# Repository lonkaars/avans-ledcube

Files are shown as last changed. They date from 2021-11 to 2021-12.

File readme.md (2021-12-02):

# avans-ledcube

(in dutch again haha)

onze ledcube is iets anders dan de gemiddelde ledcube. onze leds zijn
aangesloten als een 8x8 matrix waarbij alle anodes in rijen, en alle cathodes
in kolommen zijn verbonden. hierdoor gebruikt onze ledcube maar acht
weerstanden inplaats van zestien, en geen transistoren of mosfets. ook worden
maar drie uitgangen van de arduino gebruikt voor de seriële ingang, seriële
klok, en de latch klok van het shiftregister.

## coole functies

- algoritme om lege scanrijen over te slaan voor een hogere felheid
- instelbare lengte en volgorde van de effecten die afspelen
- makkelijk uitbereidbaar met nieuwe effecten
- goed gedocumenteerd
- opgesplitst in losse bestanden voor overzichtelijkheid
- ingebouwde led map zodat je coordinaten kunt gebruiken in je animatiecode
- veganistisch vriendelijk

## software

de software is als gevolg van de ongewone aansluitingswijze ook anders
ingericht. de atmega328p heeft ingebouwde pwm timers, die je zou kunnen
gebruiken om snel door de vier lagen van de ledcube heen te schakelen. omdat
deze timers los van je code draaien kun je de ingebouwde `delay()` gewoon
gebruiken om de animaties makkelijker te implementeren, maar dit werkt alleen
wanneer je transistoren gebruikt en ze direct op pwm uitgangen aansluit.

daarom gebruikt onze software geen `delay()` of andere 'blokkerende' functies,
maar timers. dit zorgt ervoor dat de ingebouwde `loop()` functie van de arduino
vaak genoeg draait om het te laten lijken alsof alle led's van de ledcube
tegelijkertijd aan zijn.

de software is opgesplitst in losse bestanden om overzichtelijkheid te
behouden. alle documentatie bevindt zich in de header (.h) bestanden, is in het
engels, en is in doxygen formaat. hier is een beknopte beschrijving van de
bestanden:

```
software/
├── animation.h      --
├── animation.ino    helpfuncties voor animaties
├── consts.h         algemene constantes
├── effects.h        bevat ook opties voor de diavoorstelling van animaties
├── effects.ino      de animaties die weergeven worden
├── readme.md        dit bestand
├── scan.h           --
├── scan.ino         functies omtrent het schakelen van de rijen
├── shift.h          --
├── shift.ino        functies die het shiftregister besturen
├── software.h       --
├── software.ino     hoofdbestand/ingangspunt
├── util.h           --
└── util.ino         gereedschapsfuncties
```

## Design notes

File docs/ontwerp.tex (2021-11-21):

\documentclass[12pt, a4paper, dutch]{article}

\usepackage[margin=1in]{geometry}
\usepackage{circuitikz}
\usepackage{float}
\usepackage{babel}
\usepackage{siunitx}
\usepackage{amsmath}
\usepackage{scalerel}
\usepackage{csquotes}
\usepackage{parskip}
\usepackage{unicode-math}
\usepackage{fontspec}
\usepackage{tabularx}
\usepackage{booktabs}
\usepackage{graphicx}
\usepackage{pgfplots}
\usepackage{color}
\usepackage{hyperref}

\setmainfont{TeX Gyre Schola}
\setmathfont{TeX Gyre Schola Math}
\setmonofont{JetBrainsMono Nerd Font}
\sisetup{
	group-separator = {.},
	output-decimal-marker = {,}
}

\pgfplotsset{compat=newest}

\usetikzlibrary{calc}
\usetikzlibrary{shapes.geometric}
\usetikzlibrary{arrows.meta,arrows}
\usetikzlibrary{positioning}
\tikzset{
	initial/.style={circle, fill},
	final/.style={solid, double=white, circle, fill, thick, draw},
	decision/.style={diamond, black, draw},
	action/.style={rectangle, draw, rounded corners, align=center},
	arrow/.style={draw, -{Latex[length=3mm]}, thick, rounded corners}
}

\bigskipamount=7mm
\medskipamount=4mm
\parindent=0mm

\begin{document}

\begin{center}
\textbf{Ontwerp} \hspace{2mm} project ledcube \hfill \textbf{Loek Le Blansch}
(2180996)\\
\today \hfill \textbf{Sybren van den Heuvel} (2191465)
\end{center}

\medskip

Dit document maakt gebruik van hyperlinks, dus je kunt klikken op de blokken met
\emph{benadrukte tekst} om naar de definitie van dat blok te gaan.

\section{Software ontwerp}

\subsection*{Overzicht}\label{overzicht}
\begin{center}
\begin{tikzpicture}[node distance=1.5cm]
\node[initial] (initial) at (0,0) {};
\node[action, below of = initial] (setup) {\hyperref[init]{\emph{Initialisatie}}};
\node[decision, below of = setup] (comb) {};
\node[action, below of = comb] (loop) {\hyperref[loop]{\emph{Loop}}};

\draw [arrow] (initial) -- (setup);
\draw [arrow] (setup) -- (comb);
\draw [arrow] (comb) -- (loop);
\draw [arrow] (loop) -- ++(0, -1) -- ++(-2, 0) |- (comb);

\end{tikzpicture}
\end{center}

\subsection*{Initialisatie}\label{init}
\begin{center}
\begin{tikzpicture}[node distance=1.5cm]
\node[initial] (initial) at (0,0) {};

\node[action, below = 1cm of initial] (mkvars) {Maak globale variabelen voor\\de
	huidige staat van de led's};

\node[action, below = 1cm of mkvars] (pinmode) {Stel pin 2, 3, en 4 in als
	output\\voor het shiftregister};

\node[action, below = 1cm of pinmode] (frametimecalc) {Bereken hoe lang een beeld
	duurt\\in milliseconden afhankelijk van\\de verversingssnelheid};

\node[final, below of = frametimecalc] (final) {};

\draw [arrow] (initial) -- (mkvars);
\draw [arrow] (mkvars) -- (pinmode);
\draw [arrow] (pinmode) -- (frametimecalc);
\draw [arrow] (frametimecalc) -- (final);

\end{tikzpicture}
\end{center}

\subsection*{Loop}\label{loop}
\begin{center}
\begin{tikzpicture}[node distance=2cm]
\node[initial] (initial) at (0,0) {};

\node[action, below of = initial] (gettime)
	{Sla op hoe lang de arduino\\aan is in milliseconden};

\node[action, below of = gettime] (calcfxindex)
	{Bereken welk effect afgespeeld moet worden};

\node[action, below of = calcfxindex] (calcfxtime)
	{Bereken hoe lang het huidige effect al bezig is};

\node[action, below of = calcfxtime] (fxexec)
	{Voer de functie van het huidige effect uit};

\node[action, below of = fxexec] (updateregs)
	{Update de status van de led's};

\node[final, below of = updateregs] (final) {};

\draw [arrow] (initial) -- (gettime);
\draw [arrow] (gettime) -- (calcfxindex);
\draw [arrow] (calcfxindex) -- (calcfxtime);
\draw [arrow] (calcfxtime) -- (fxexec);
\draw [arrow] (fxexec) -- (updateregs);
\draw [arrow] (updateregs) -- (final);

\end{tikzpicture}
\end{center}

\section{Hardware}

\subsection{Schema}

\begin{center}
\includegraphics[
	clip,
	trim=21mm 83mm 22mm 13mm,
	width=\textwidth
]{./schema.pdf}
\end{center}

\subsection{PCB}
\begin{center}
\includegraphics[
	clip,
	trim=13mm 119mm 124mm 13mm,
	width=\textwidth
]{./pcb.pdf}
\end{center}

\subsection{Bedrading (3D)}

Dit is een 3D-weergave van de bedrading van de led cube. In deze weergave zie je
duidelijk dat de led cube bestaat uit een 8$\times$8-matrix die twee keer is
dubbelgevouwd. Hier zijn de roze verbindingen de anode's van de led's, en de blauwe
de cathode's.

\begin{center}
\includegraphics[
	width=0.4\textwidth
]{./red.png}
\hspace{1cm}
\includegraphics[
	width=0.4\textwidth
]{./blue.png}
\end{center}

\section{Functiebeschrijving}

\includegraphics[
	clip,
	trim=24.5mm 180mm 24.5mm 24.5mm,
	width=\textwidth
]{./functiebeschrijving.pdf}

\section{Blokschema}

\includegraphics[
	width=\textwidth
]{./blokschema.jpeg}

\end{document}

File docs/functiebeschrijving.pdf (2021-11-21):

| Waarom zit onderdeel in de Ledcube? | Hoe is het onderdeel opgebouwd? Wat is het voor onderdeel? Hoe ziet het er uit? | Wat doet het onderdeel?
Shiftregister | Het shiftregister zit in de Ledcube om het aantal uitgangen te vergroten en zo de ledjes individueel aan te sturen. | Een shiftregister is digitaal circuit van een reeks flipflops achter elkaar. Waarbij de ene uitgang van de flipflop is verbonden met de ingang van de volgende. | Een shiftregister is een register met een kloksignaal, wat zorgt dat de data in het register (bits) van de ene plek naar de andere plek kan ‘’shiften’’ en kan ze tijdelijk opslaan.
Led | De ledjes zitten in de Ledcube om de animaties op weer te geven. | Een light emmiting diode (Led) | De led zal de animaties visualiseren.

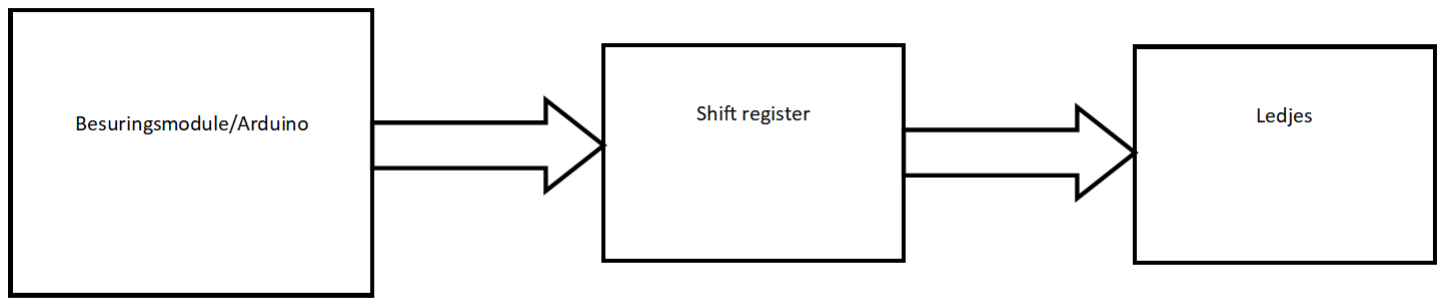
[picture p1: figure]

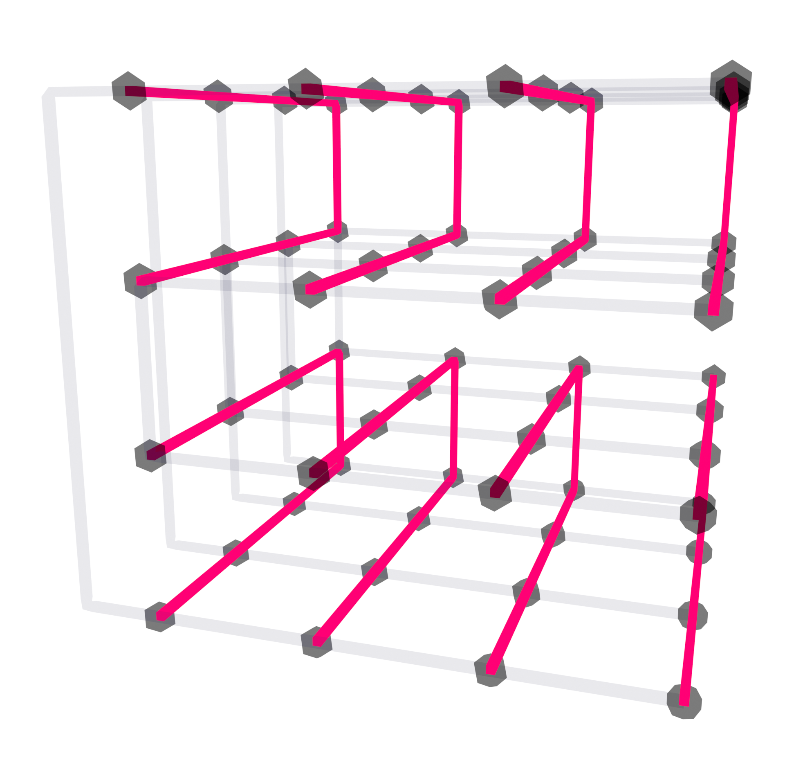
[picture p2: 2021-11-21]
docs/red.png

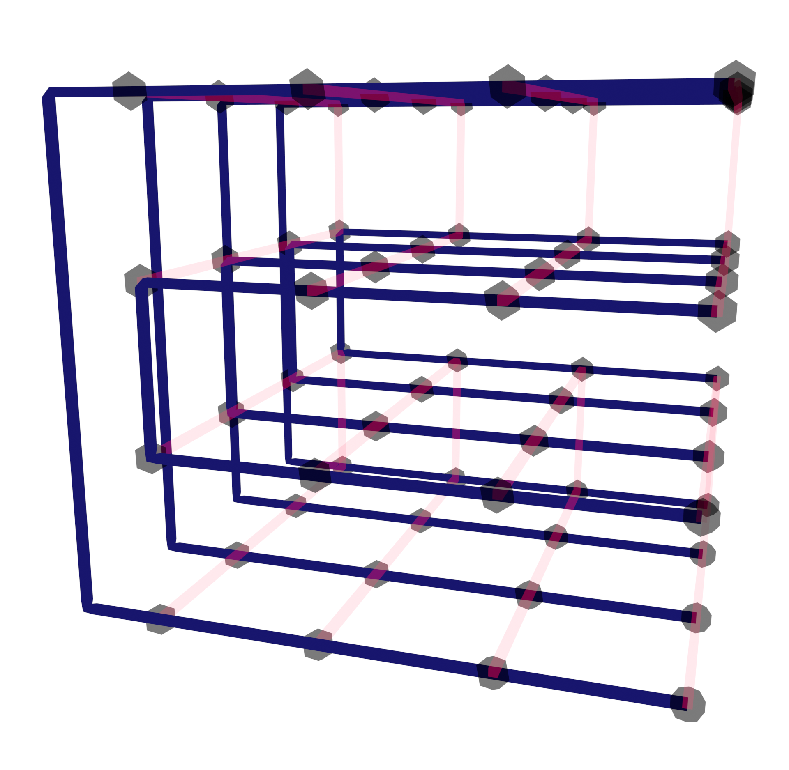
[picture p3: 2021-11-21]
docs/blue.png

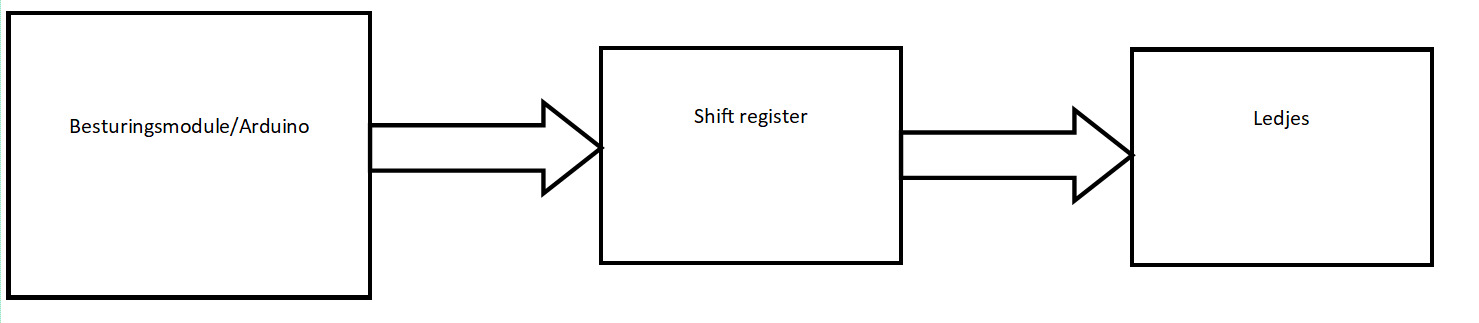
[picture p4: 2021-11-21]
docs/blokschema.jpeg

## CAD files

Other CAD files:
hardware/wiring.blend

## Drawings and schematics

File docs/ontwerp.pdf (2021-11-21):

Ontwerp project ledcube | Loek Le Blansch (2180996)
21 november 2021 | Sybren van den Heuvel (2191465)

Dit document maakt gebruik van hyperlinks, dus je kunt klikken op de blokken met benadrukte tekst om naar de definitie van dat blok te gaan.

## 1 Software ontwerp

### Overzicht

Initialisatie

Loop

### Initialisatie

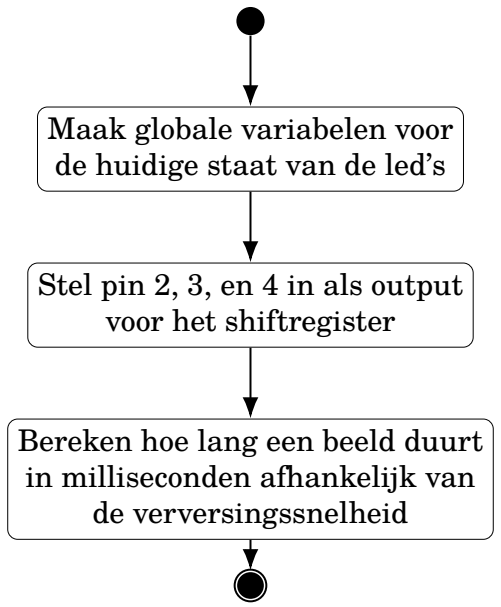
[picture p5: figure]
Maak globale variabelen voor de huidige staat van de led’s; Stel pin 2, 3, en 4 in als output voor het shiftregister; Bereken hoe lang een beeld duurt in milliseconden afhankelijk van de verversingssnelheid
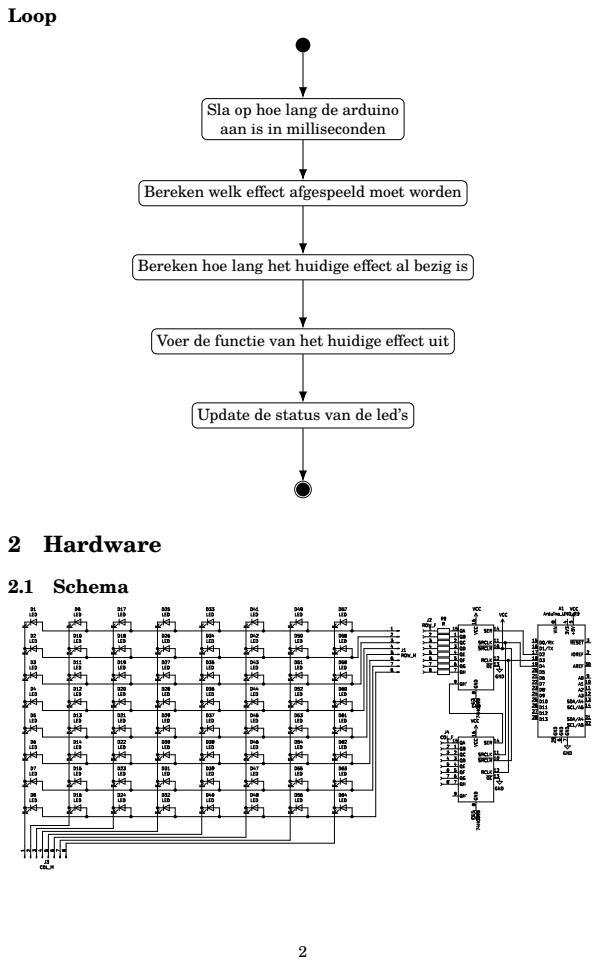
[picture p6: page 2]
Loop; 2 Hardware; 2.1 Schema

Sla op hoe lang de arduino
aan is in milliseconden

Bereken welk effect afgespeeld moet worden

Bereken hoe lang het huidige effect al bezig is

Voer de functie van het huidige effect uit

Update de status van de led’s

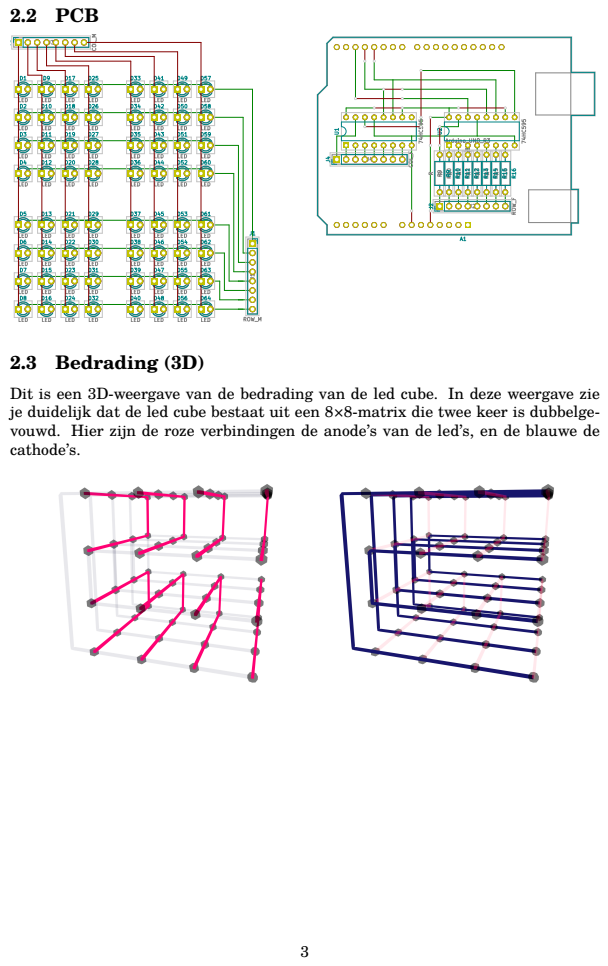
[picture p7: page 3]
2.2 PCB; 2.3 Bedrading (3D)

Dit is een 3D-weergave van de bedrading van de led cube. In deze weergave zie
je duidelijk dat de led cube bestaat uit een 8×8-matrix die twee keer is dubbelge-
vouwd. Hier zijn de roze verbindingen de anode’s van de led’s, en de blauwe de
cathode’s.

## 3 Functiebeschrijving Waarom zit

| onderdeel in de Ledcube? | Hoe is het onderdeel opgebouwd? Wat is het voor onderdeel? Hoe ziet het er uit? | Wat doet het onderdeel?
Shiftregister | Het shiftregister zit in de Ledcube om het aantal uitgangen te vergroten en zo de ledjes individueel aan te sturen. | Een shiftregister is digitaal circuit van een reeks flipflops achter elkaar. Waarbij de ene uitgang van de flipflop is verbonden met de ingang van de volgende. | Een shiftregister is een register met een kloksignaal, wat zorgt dat de data in het register (bits) van de ene plek naar de andere plek kan ‘’shiften’’ en kan ze tijdelijk opslaan.
Led | De ledjes zitten in de Ledcube om de animaties op weer te geven. | Een light emmiting diode (Led) | De led zal de animaties visualiseren.

## 4 Blokschema

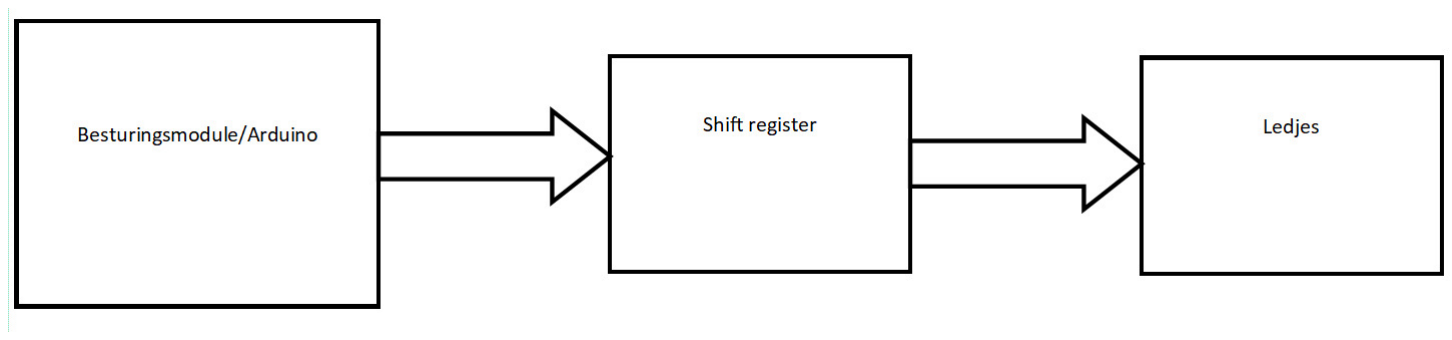
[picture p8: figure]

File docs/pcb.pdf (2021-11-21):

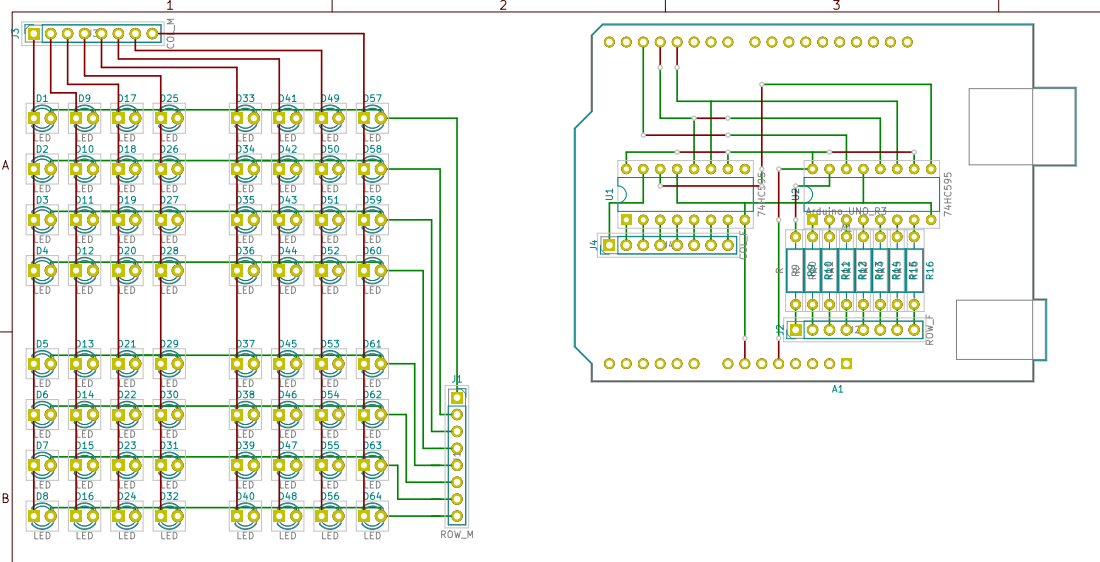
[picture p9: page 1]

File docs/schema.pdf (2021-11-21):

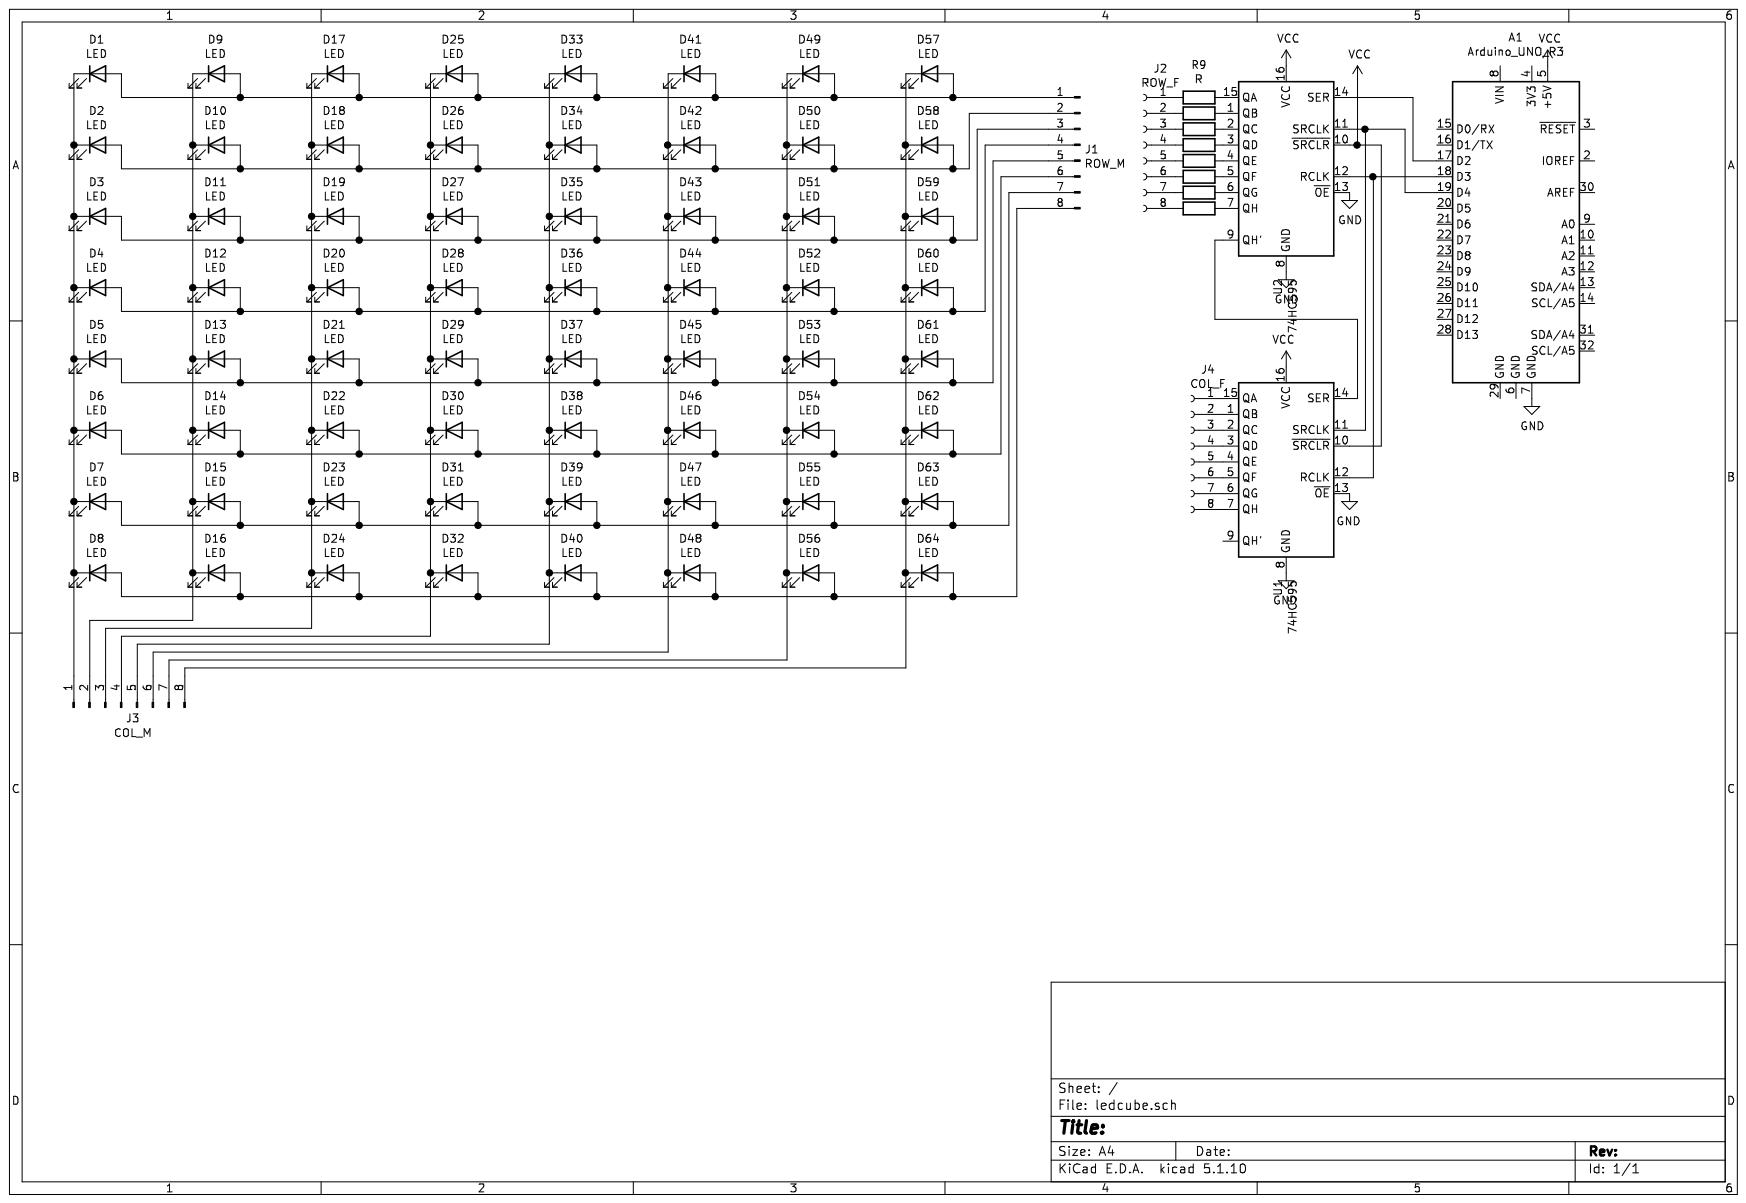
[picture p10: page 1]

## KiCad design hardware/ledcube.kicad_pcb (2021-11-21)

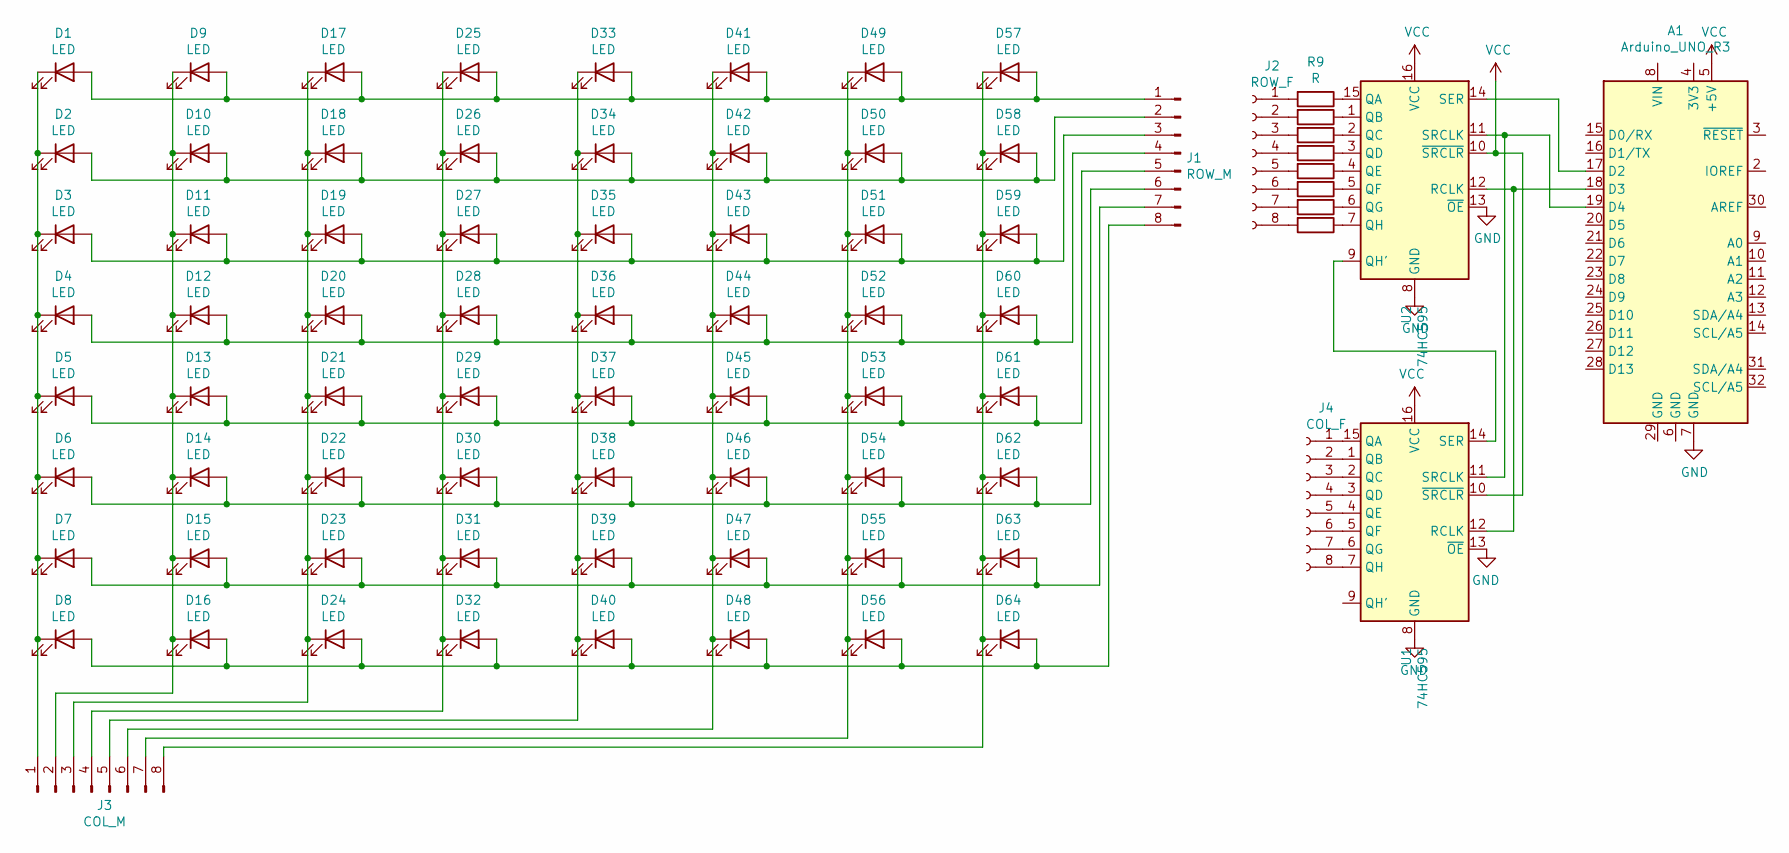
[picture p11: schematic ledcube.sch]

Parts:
A1: Arduino_UNO_R3
D1, D2, D3, D4, D5, D6, D7, D8, D9, D10, D11, D12, D13, D14, D15, D16, D17, D18, D19, D20, D21, D22, D23, D24, D25, D26, D27, D28, D29, D30, D31, D32, D33, D34, D35, D36, D37, D38, D39, D40, D41, D42, D43, D44, D45, D46, D47, D48, D49, D50, D51, D52, D53, D54, D55, D56, D57, D58, D59, D60, D61, D62, D63, D64: LED; LED_D3.0mm
J1: ROW_M; PinSocket_1x08_P2.54mm_Vertical
J2: ROW_F; PinHeader_1x08_P2.54mm_Vertical
J3: COL_M; PinSocket_1x08_P2.54mm_Vertical
J4: COL_F; PinHeader_1x08_P2.54mm_Vertical
R9, R10, R11, R12, R13, R14, R15, R16: R; R_Axial_DIN0207_L6.3mm_D2.5mm_P10.16mm_Horizontal
U1, U2: 74HC595

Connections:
GND: A1.7 (GND), U1.8 (GND), U1.13 (~OE), U2.8 (GND), U2.13 (~OE)
unnamed: A1.17 (D2), U2.14 (SER)
unnamed: A1.18 (D3), U1.12 (RCLK), U2.12 (RCLK)
unnamed: A1.19 (D4), U1.11 (SRCLK), U2.11 (SRCLK)
unnamed: D1.1 (K), D2.1 (K), D3.1 (K), D4.1 (K), D5.1 (K), D6.1 (K), D7.1 (K), D8.1 (K), J3.1
unnamed: D1.2 (A), D9.2 (A), D17.2 (A), D25.2 (A), D33.2 (A), D41.2 (A), D49.2 (A), D57.2 (A), J1.1
unnamed: D9.1 (K), D10.1 (K), D11.1 (K), D12.1 (K), D13.1 (K), D14.1 (K), D15.1 (K), D16.1 (K), J3.2
unnamed: D2.2 (A), D10.2 (A), D18.2 (A), D26.2 (A), D34.2 (A), D42.2 (A), D50.2 (A), D58.2 (A), J1.2
unnamed: D3.2 (A), D11.2 (A), D19.2 (A), D27.2 (A), D35.2 (A), D43.2 (A), D51.2 (A), D59.2 (A), J1.3
unnamed: D4.2 (A), D12.2 (A), D20.2 (A), D28.2 (A), D36.2 (A), D44.2 (A), D52.2 (A), D60.2 (A), J1.4
unnamed: D5.2 (A), D13.2 (A), D21.2 (A), D29.2 (A), D37.2 (A), D45.2 (A), D53.2 (A), D61.2 (A), J1.5
unnamed: D6.2 (A), D14.2 (A), D22.2 (A), D30.2 (A), D38.2 (A), D46.2 (A), D54.2 (A), D62.2 (A), J1.6
unnamed: D7.2 (A), D15.2 (A), D23.2 (A), D31.2 (A), D39.2 (A), D47.2 (A), D55.2 (A), D63.2 (A), J1.7
unnamed: D8.2 (A), D16.2 (A), D24.2 (A), D32.2 (A), D40.2 (A), D48.2 (A), D56.2 (A), D64.2 (A), J1.8
unnamed: D17.1 (K), D18.1 (K), D19.1 (K), D20.1 (K), D21.1 (K), D22.1 (K), D23.1 (K), D24.1 (K), J3.3
unnamed: D25.1 (K), D26.1 (K), D27.1 (K), D28.1 (K), D29.1 (K), D30.1 (K), D31.1 (K), D32.1 (K), J3.4
unnamed: D33.1 (K), D34.1 (K), D35.1 (K), D36.1 (K), D37.1 (K), D38.1 (K), D39.1 (K), D40.1 (K), J3.5
unnamed: D41.1 (K), D42.1 (K), D43.1 (K), D44.1 (K), D45.1 (K), D46.1 (K), D47.1 (K), D48.1 (K), J3.6
unnamed: D49.1 (K), D50.1 (K), D51.1 (K), D52.1 (K), D53.1 (K), D54.1 (K), D55.1 (K), D56.1 (K), J3.7
unnamed: D57.1 (K), D58.1 (K), D59.1 (K), D60.1 (K), D61.1 (K), D62.1 (K), D63.1 (K), D64.1 (K), J3.8
unnamed: J2.1, R9.2
unnamed: J2.2, R10.2
unnamed: J2.3, R11.2
unnamed: J2.4, R12.2
unnamed: J2.5, R13.2
unnamed: J2.6, R14.2
unnamed: J2.7, R15.2
unnamed: J2.8, R16.2
unnamed: J4.1, U1.15 (QA)
unnamed: J4.2, U1.1 (QB)
unnamed: J4.3, U1.2 (QC)
unnamed: J4.4, U1.3 (QD)
unnamed: J4.5, U1.4 (QE)
unnamed: J4.6, U1.5 (QF)
unnamed: J4.7, U1.6 (QG)
unnamed: J4.8, U1.7 (QH)
unnamed: R9.1, U2.15 (QA)
unnamed: R10.1, U2.1 (QB)
unnamed: R11.1, U2.2 (QC)
unnamed: R12.1, U2.3 (QD)
unnamed: R13.1, U2.4 (QE)
unnamed: R14.1, U2.5 (QF)
unnamed: R15.1, U2.6 (QG)
unnamed: R16.1, U2.7 (QH)
unnamed: U1.14 (SER), U2.9 (QH')
VCC: A1.5 (+5V), U1.10 (~SRCLR), U1.16 (VCC), U2.10 (~SRCLR), U2.16 (VCC)

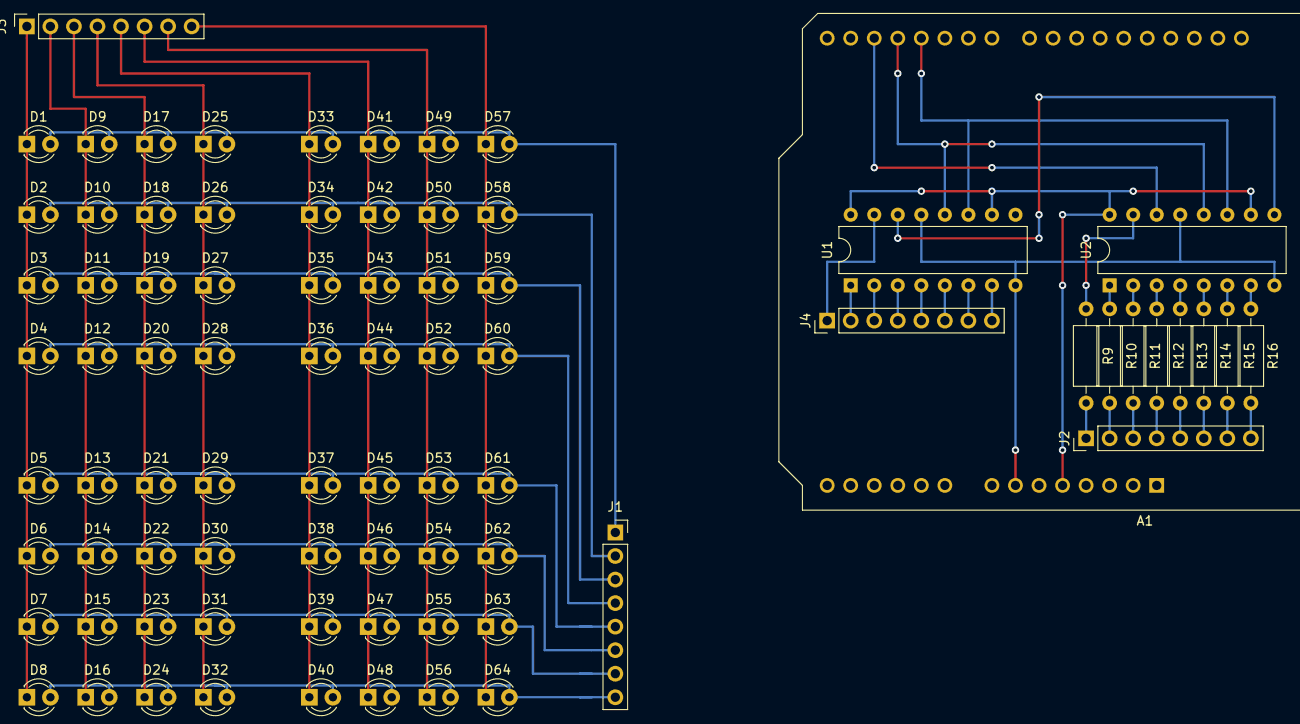
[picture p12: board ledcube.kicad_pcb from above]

Board: 2 copper layers, 79 parts (0 on the bottom side), 46 nets.

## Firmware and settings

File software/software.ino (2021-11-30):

#include "software.h"
#include "consts.h"
#include "effects.h"
#include "scan.h"

bool led_state[64];
bool scan_enable = true;
#ifndef SLIDESHOW_DURATION
unsigned long slideshow_length_total;
#endif

void setup() {
	pinMode(PINOUT_SER, OUTPUT);
	pinMode(PINOUT_SCK, OUTPUT);
	pinMode(PINOUT_LCK, OUTPUT);

	pinMode(PINOUT_NOISE, INPUT); // random noise voor RNG
	randomSeed(analogRead(PINOUT_NOISE));

	#ifdef DEBUG
	Serial.begin(CONFIG_SERIAL_BAUD);
	Serial.println("startup");
	#endif

	#ifndef SLIDESHOW_DURATION
	for(int i = 0; i < SLIDESHOW_SIZE; i++)
		slideshow_length_total += slideshow_lengths[i];
	#endif
}

void loop() {
	unsigned long current_time = millis();

	#ifdef SLIDESHOW_DURATION
	unsigned long slide_time = current_time % SLIDESHOW_DURATION;
	unsigned int  slide_index = (current_time / SLIDESHOW_DURATION) % SLIDESHOW_SIZE;
	#else
	unsigned long slide_time = current_time % slideshow_length_total;
	unsigned int  slide_index = 0;
	unsigned long slide_sum = 0;
	for(int i = 0; i < SLIDESHOW_SIZE; i++) {
		slide_sum += slideshow_lengths[i];
		if (slide_time >= slide_sum) continue;
		slide_index = i;
		slide_time -= slide_sum - slideshow_lengths[i];
		break;
	}
	#endif

	// #ifdef DEBUG
	// print_ani_debug(slide_index, slide_time);
	// #endif
	slideshow_effects[slide_index](slide_time);

	if (scan_enable) scan();
}

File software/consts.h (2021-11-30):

#pragma once

// pinouts
#define PINOUT_SCK 4
#define PINOUT_SER 2
#define PINOUT_LCK 3
#define PINOUT_NOISE A0

// debug options
// #define CONFIG_SERIAL_BAUD 115200
// #define DEBUG

/**
 * @brief map 3D cube coordinates to `led_state` indices
 *
 * usage: `led_state[led_map[x + 4*y + 16*z]]`
 */
const unsigned int led_map[64] = {
	0x31, 0x21, 0x11, 0x01,
	0x33, 0x23, 0x13, 0x03,
	0x35, 0x25, 0x15, 0x05,
	0x37, 0x27, 0x17, 0x07,
                  
	0x30, 0x20, 0x10, 0x00,
	0x32, 0x22, 0x12, 0x02,
	0x34, 0x24, 0x14, 0x04,
	0x36, 0x26, 0x16, 0x06,
                  
	0x38, 0x28, 0x18, 0x08,
	0x3a, 0x2a, 0x1a, 0x0a,
	0x3c, 0x2c, 0x1c, 0x0c,
	0x3e, 0x2e, 0x1e, 0x0e,
                  
	0x39, 0x29, 0x19, 0x09,
	0x3b, 0x2b, 0x1b, 0x0b,
	0x3d, 0x2d, 0x1d, 0x0d,
	0x3f, 0x2f, 0x1f, 0x0f,
};

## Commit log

2021-11-21 design document
    [wiring.blend]
2021-11-26 added documentation comments and led map
2021-11-27 implemented animation 3
    also fixed memory leak caused by pointer arithmetic -> 0xf0 != 0x10
    [animation.ino, consts.h, effects.ino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]
2021-11-30 fix compiler warnings and ready for testing `optimize_scan()`
    [effects.ino, scan.ino, util.ino]
2021-11-30 fix animation 1 and 3 TODO: 2
    [animation.ino, consts.h, effects.ino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]
2021-11-30 fixed(?) optimize_scan, testing tomorrow...
    [animation.ino, scan.ino]
2021-12-02 fix scan_optimize and update readme
    [scan.ino]
